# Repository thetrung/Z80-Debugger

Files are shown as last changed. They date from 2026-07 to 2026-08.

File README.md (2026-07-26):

# Z80 Debugger 
Another PCB made for Z80 + PIC18F4520 to debug, test-run & verify code.

### Note
I have never had a real working Z80 before so this board is designed to test that if I can get one.

### Preview 
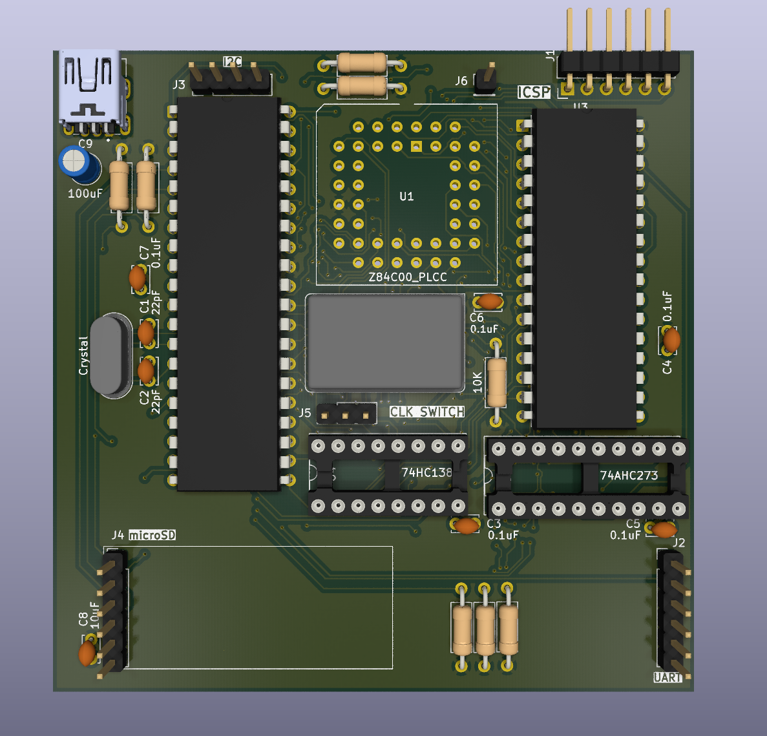
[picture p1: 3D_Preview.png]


### Schematic 
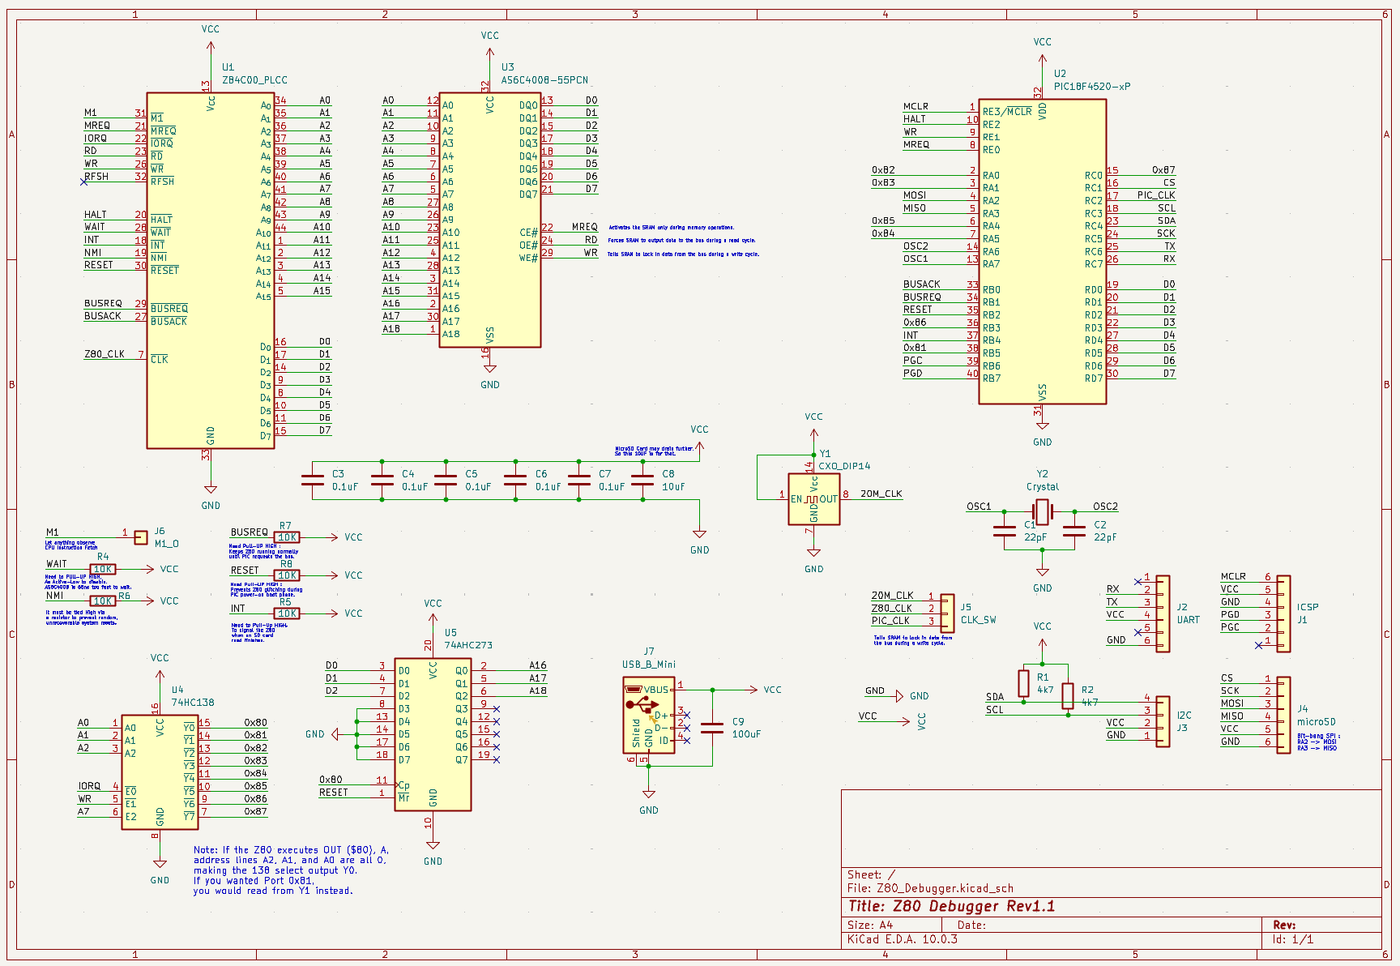
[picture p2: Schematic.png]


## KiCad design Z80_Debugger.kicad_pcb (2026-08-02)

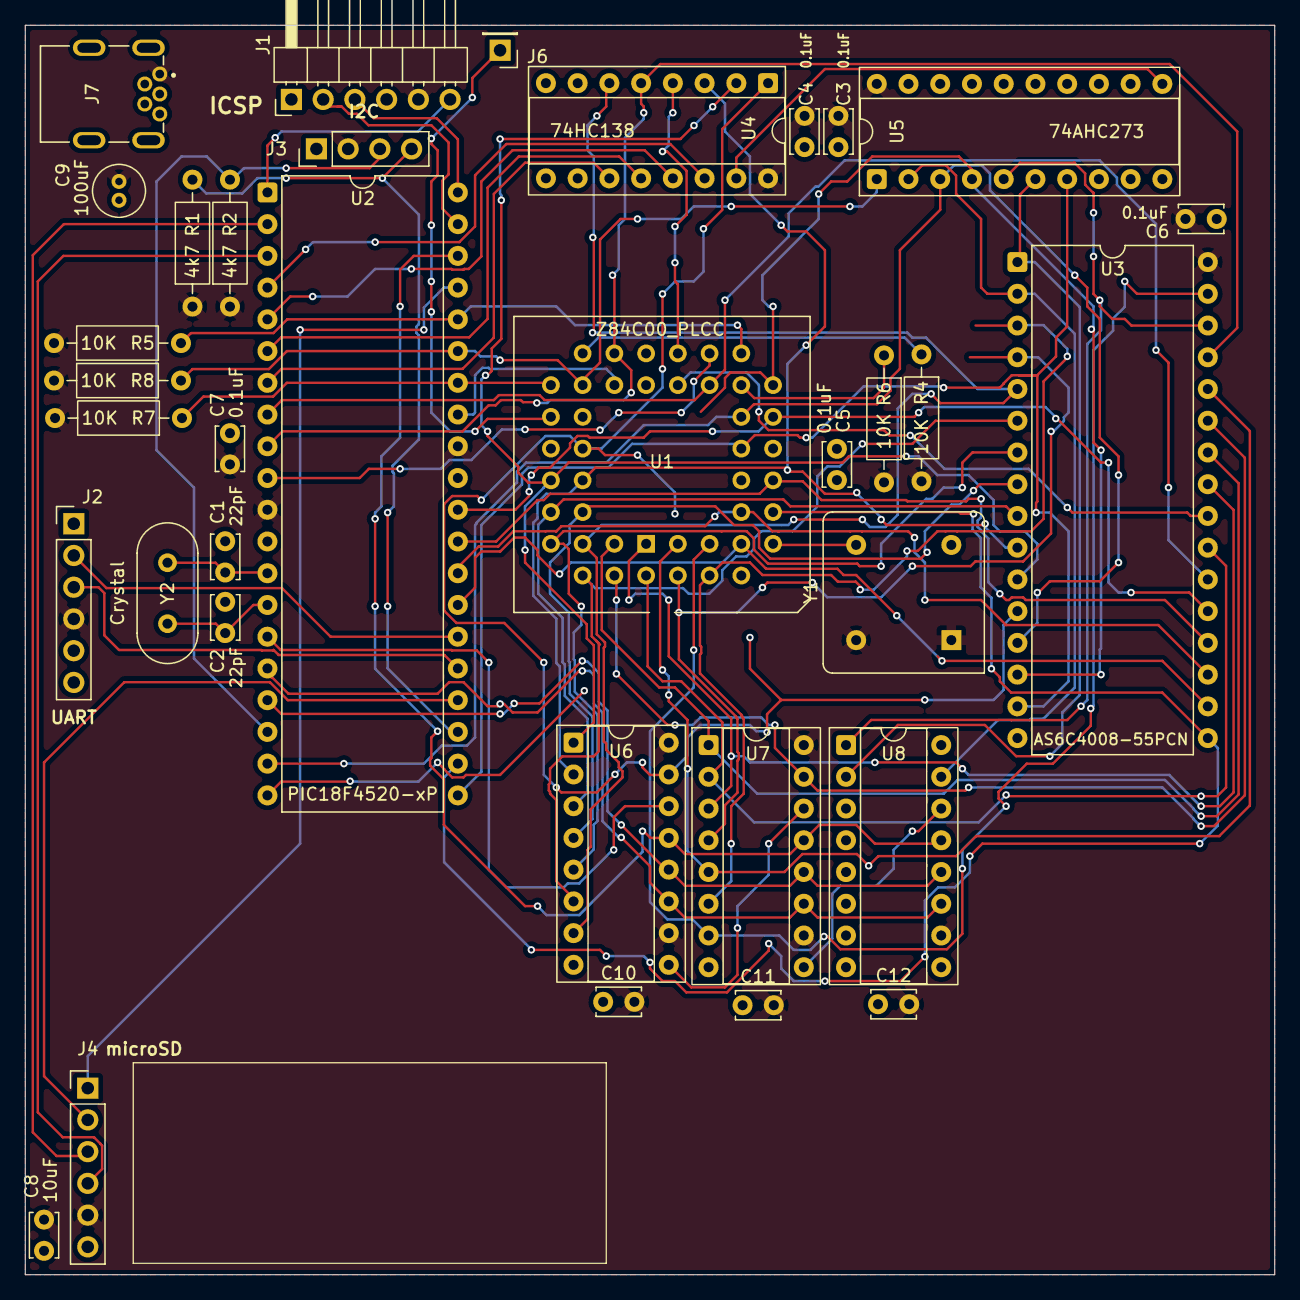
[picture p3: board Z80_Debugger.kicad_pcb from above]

Board: 2 copper layers, 100.0 x 100.0 mm, 35 parts (0 on the bottom side), 66 nets.

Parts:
C1, C2: 22pF; C_Disc_D3.4mm_W2.1mm_P2.50mm
C3, C4, C5, C6, C7, C10, C11, C12: 0.1uF; C_Disc_D3.4mm_W2.1mm_P2.50mm
C8: 10uF; C_Disc_D3.4mm_W2.1mm_P2.50mm
C9: 100uF; C_Radial_D4.0mm_H5.0mm_P1.50mm
J1: ICSP; PinHeader_1x06_P2.54mm_Horizontal
J2: UART; PinHeader_1x06_P2.54mm_Vertical
J3: I2C; PinHeader_1x04_P2.54mm_Vertical
J4: microSD; PinHeader_1x06_P2.54mm_Vertical
J6: M1_O; PinHeader_1x01_P2.54mm_Vertical
J7: USB_B_Mini; USB_MINI_B_90_Angled
R1, R2: 4k7; R_Axial_DIN0207_L6.3mm_D2.5mm_P10.16mm_Horizontal
R4, R5, R6, R7, R8: 10K; R_Axial_DIN0207_L6.3mm_D2.5mm_P10.16mm_Horizontal
U1: Z84C00_PLCC; PLCC-44_THT-Socket
U2: PIC18F4520-xP; DIP-40_W15.24mm
U3: AS6C4008-55PCN; DIP-32_W15.24mm
U4: 74HC138; DIP-16_W7.62mm_Socket
U5: 74AHC273; DIP-20_W7.62mm_Socket
U6, U7, U8: 74HC595; DIP-16_W7.62mm_Socket
Y1: CXO_DIP8; Oscillator_DIP-8
Y2: Crystal; Crystal_HC49-4H_Vertical

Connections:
/0x80: U4.15 (~Y0), U5.11 (Cp)
/0x81: U2.4 (RA2), U4.14 (~Y1)
/0x82: U2.5 (RA3), U4.13 (~Y2)
/0x83: U2.6 (RA4), U4.12 (~Y3)
/0x84: U2.7 (RA5), U4.11 (~Y4)
/595E: U2.38 (RB5), U6.13 (~OE), U7.13 (~OE), U8.13 (~OE)
/A0: U1.34 (A_{0}), U3.12 (A0), U4.1 (A0), U6.15 (QA)
/A1: U1.35 (A_{1}), U3.11 (A1), U4.2 (A1), U6.1 (QB)
/A2: U1.36 (A_{2}), U3.10 (A2), U4.3 (A2), U6.2 (QC)
/A3: U1.37 (A_{3}), U3.9 (A3), U6.3 (QD)
/A4: U1.38 (A_{4}), U3.8 (A4), U6.4 (QE)
/A5: U1.39 (A_{5}), U3.7 (A5), U6.5 (QF)
/A6: U1.40 (A_{6}), U3.6 (A6), U6.6 (QG)
/A7: U1.41 (A_{7}), U3.5 (A7), U4.6 (E2), U6.7 (QH)
/A8: U1.42 (A_{8}), U3.27 (A8), U7.15 (QA)
/A9: U1.43 (A_{9}), U3.26 (A9), U7.1 (QB)
/A10: U1.44 (A_{10}), U3.23 (A10), U7.2 (QC)
/A11: U1.1 (A_{11}), U3.25 (A11), U7.3 (QD)
/A12: U1.2 (A_{12}), U3.4 (A12), U7.4 (QE)
/A13: U1.3 (A_{13}), U3.28 (A13), U7.5 (QF)
/A14: U1.4 (A_{14}), U3.3 (A14), U7.6 (QG)
/A15: U1.5 (A_{15}), U3.31 (A15), U7.7 (QH)
/A16: U3.2 (A16), U5.2 (Q0), U8.15 (QA)
/A17: U3.30 (A17), U5.5 (Q1), U8.1 (QB)
/A18: U3.1 (A18), U5.6 (Q2), U8.2 (QC)
/BUSACK: U1.27 (~BUSACK), U2.33 (RB0)
/BUSREQ: R7.1, U1.29 (~BUSREQ), U2.34 (RB1)
/CS: J4.1, U2.37 (RB4)
/D0: U1.16 (D_{0}), U2.19 (RD0), U3.13 (DQ0), U5.3 (D0)
/D1: U1.17 (D_{1}), U2.20 (RD1), U3.14 (DQ1), U5.4 (D1)
/D2: U1.14 (D_{2}), U2.21 (RD2), U3.15 (DQ2), U5.7 (D2)
/D3: U1.9 (D_{3}), U2.22 (RD3), U3.17 (DQ3)
/D4: U1.8 (D_{4}), U2.27 (RD4), U3.18 (DQ4)
/D5: U1.10 (D_{5}), U2.28 (RD5), U3.19 (DQ5)
/D6: U1.11 (D_{6}), U2.29 (RD6), U3.20 (DQ6)
/D7: U1.15 (D_{7}), U2.30 (RD7), U3.21 (DQ7)
/HALT: U1.20 (~HALT), U2.10 (RE2)
/INT: R5.1, U1.18 (~INT), U2.36 (RB3)
/IORQ: U1.22 (~IORQ), U4.4 (~E0)
/M1: J6.1 (Pin_1_1), U1.31 (~M1)
/MCLR: J1.6, U2.1 (RE3/~MCLR)
/MISO: J4.4, U2.3 (RA1)
/MOSI: J4.3, U2.2 (RA0)
/MREQ: U1.21 (~MREQ), U2.8 (RE0), U3.22 (CE#)
/NMI: R6.1, U1.19 (~NMI)
/OSC1: C1.1, U2.13 (RA7), Y2.2
/OSC2: C2.1, U2.14 (RA6), Y2.1
/PGC: J1.2, U2.39 (RB6)
/PGD: J1.3, U2.40 (RB7)
/RCLK: U2.17 (RC2), U6.12 (RCLK), U7.12 (RCLK), U8.12 (RCLK)
/RD: U1.23 (~RD), U3.24 (OE#)
/RESET: R8.1, U1.30 (~RESET), U2.35 (RB2), U5.1 (~Mr)
/RX: J2.2, U2.26 (RC7)
/SCK: J4.2, U2.24 (RC5)
/SCL: J3.3, R2.2, U2.18 (RC3)
/SDA: J3.4, R1.2, U2.23 (RC4)
/SER: U2.15 (RC0), U6.14 (SER)
/SRCLK: U2.16 (RC1), U6.11 (SRCLK), U7.11 (SRCLK), U8.11 (SRCLK)
/TX: J2.3, U2.25 (RC6)
/WAIT: R4.1, U1.28 (~WAIT)
/WR: U1.26 (~WR), U2.9 (RE1), U3.29 (WE#), U4.5 (~E1)
/Z80_CLK: U1.7 (~CLK), Y1.5 (OUT)
GND: C1.2, C2.2, C3.1, C4.1, C5.1, C6.1, C7.1, C8.1, C9.1, C10.1, C11.1, C12.1, J1.4, J2.6, J3.1, J4.6, J7.5 (GND), J7.6 (Shield), U1.33 (GND), U2.12 (VSS), U2.31 (VSS), U3.16 (VSS), U4.8 (GND), U5.8 (D3), U5.10 (GND), U5.13 (D4), U5.14 (D5), U5.17 (D6), U5.18 (D7), U6.8 (GND), U7.8 (GND), U8.8 (GND), Y1.4 (GND)
unnamed: U6.9 (QH'), U7.14 (SER)
unnamed: U7.9 (QH'), U8.14 (SER)
VCC: C3.2, C4.2, C5.2, C6.2, C7.2, C8.2, C9.2, C10.2, C11.2, C12.2, J1.5, J2.4, J3.2, J4.5, J7.1 (VBUS), R1.1, R2.1, R4.2, R5.2, R6.2, R7.2, R8.2, U1.13 (V_{CC}), U2.11 (VDD), U2.32 (VDD), U3.32 (VCC), U4.16 (VCC), U5.20 (VCC), U6.10 (~SRCLR), U6.16 (VCC), U7.10 (~SRCLR), U7.16 (VCC), U8.10 (~SRCLR), U8.16 (VCC), Y1.1 (EN), Y1.8 (Vcc)

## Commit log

2026-07-26 init Z80_Debugger.
    [Z80_Debugger.kicad_pcb, Z80_Debugger.kicad_sch]
2026-07-26 Rev1.1: Fix PUll-UPs pins
    [Z80_Debugger.kicad_pcb, Z80_Debugger.kicad_sch]
2026-07-27 Refine SPI/MicroSD pins.
    [Z80_Debugger.kicad_pcb, Z80_Debugger.kicad_sch]
2026-07-30 Rev.2: adding 3x74HC595
    [Z80_Debugger.kicad_pcb, Z80_Debugger.kicad_sch]
2026-08-02 add pins: M1, RD, WR for Z80 Req
    [Z80_Debugger.kicad_pcb, Z80_Debugger.kicad_sch]
